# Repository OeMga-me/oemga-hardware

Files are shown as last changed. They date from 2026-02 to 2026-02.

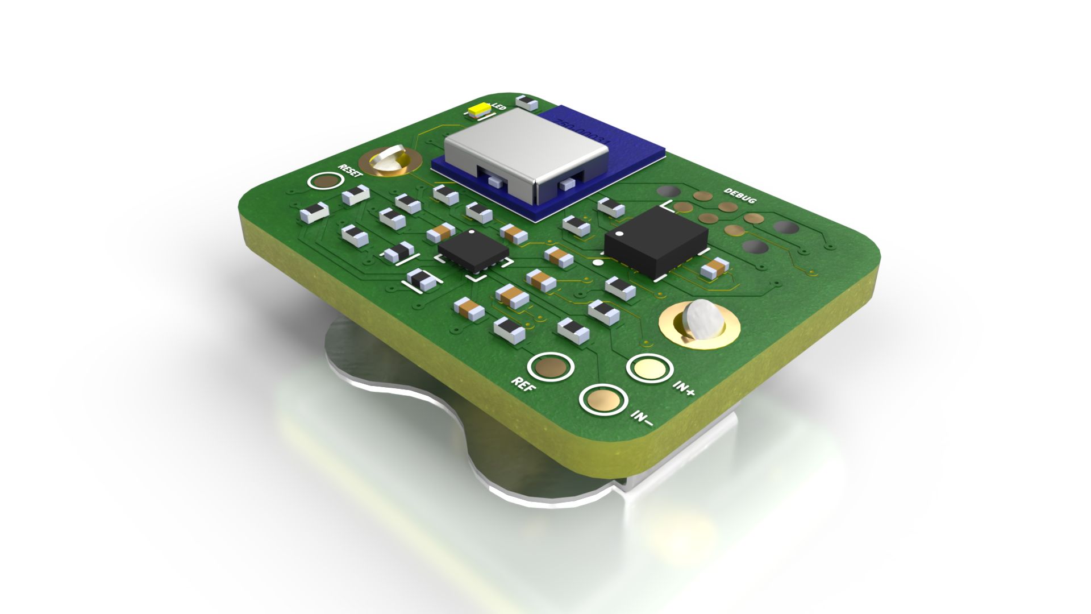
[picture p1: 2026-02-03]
hardware/Photos/1767139238420.jpeg

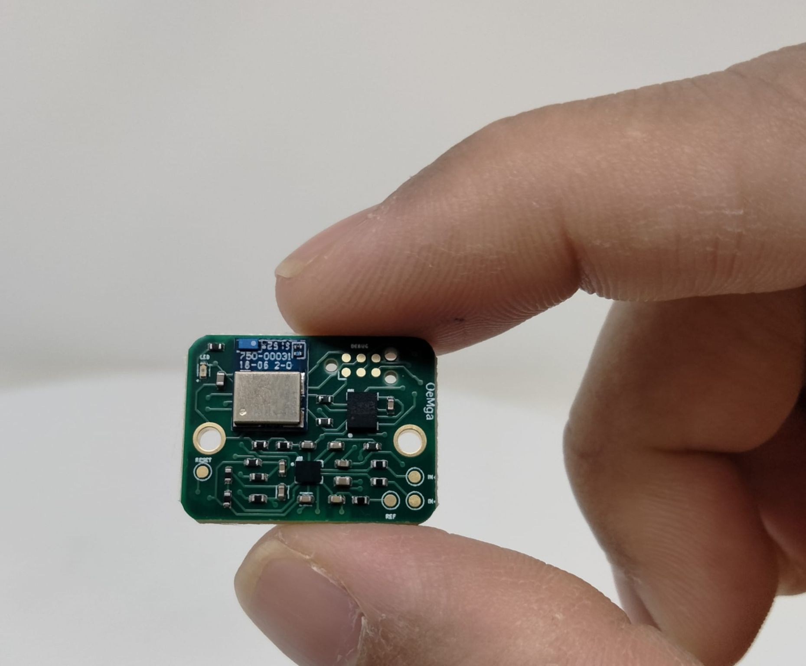
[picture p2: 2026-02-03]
hardware/Photos/1769923947562.jpeg

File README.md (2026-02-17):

<h1 align="center">OeMga.me Hardware</h1>

<p align="center">



</p>

<p align="center">
<strong>The open-source, on-device teachable bio-interaction platform.</strong>
</p>

OeMga
Copyright 2026 Adithya Pamulaparthi. Licensed under CERN-OHL-S v2.

[View Interactive 3D Model](hardware/CAD/Assembly.STL)

## The Vision
Current wearables demand that we speak their language. OeMga.me learns ours.

Today’s bio-sensors with rigid FSMs and pre-trained models, force the user to conform to the machine’s limitations. OeMga.me dismantles this paradigm. We are building the first **Teachable Bio-Interaction Platform**, where intelligence lives at the edge and evolves with you.

## The Foundation: OeMga $\alpha$
This repository hosts the open-source hardware files for the foundational module of the OeMga $\alpha$ platform: a high-precision, teachable EMG sensor.

<p align="center">
  
</p>

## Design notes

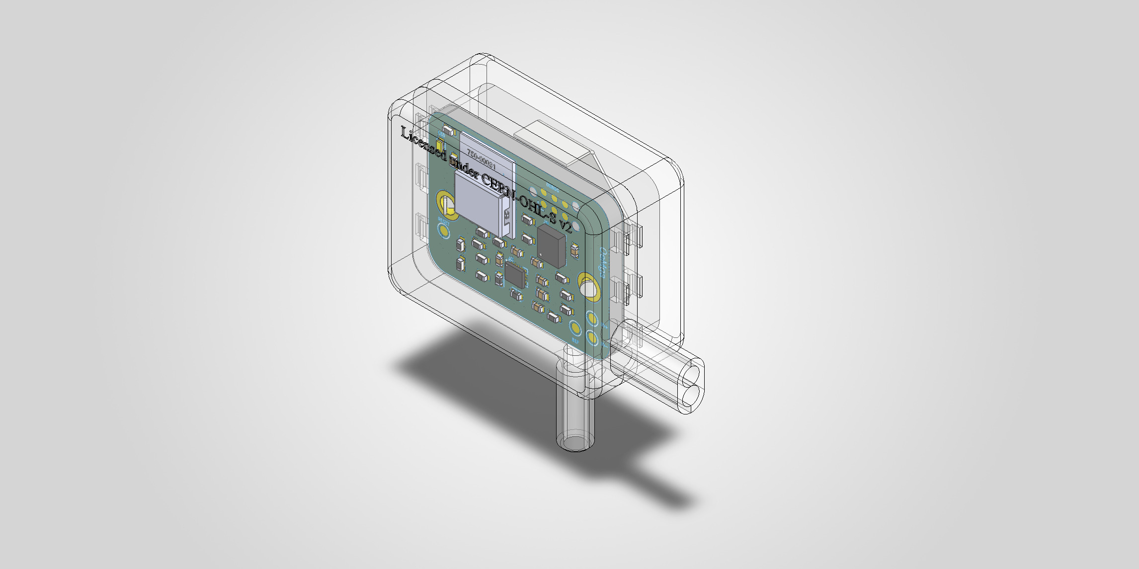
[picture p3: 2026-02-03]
hardware/CAD/Assem1.JPG

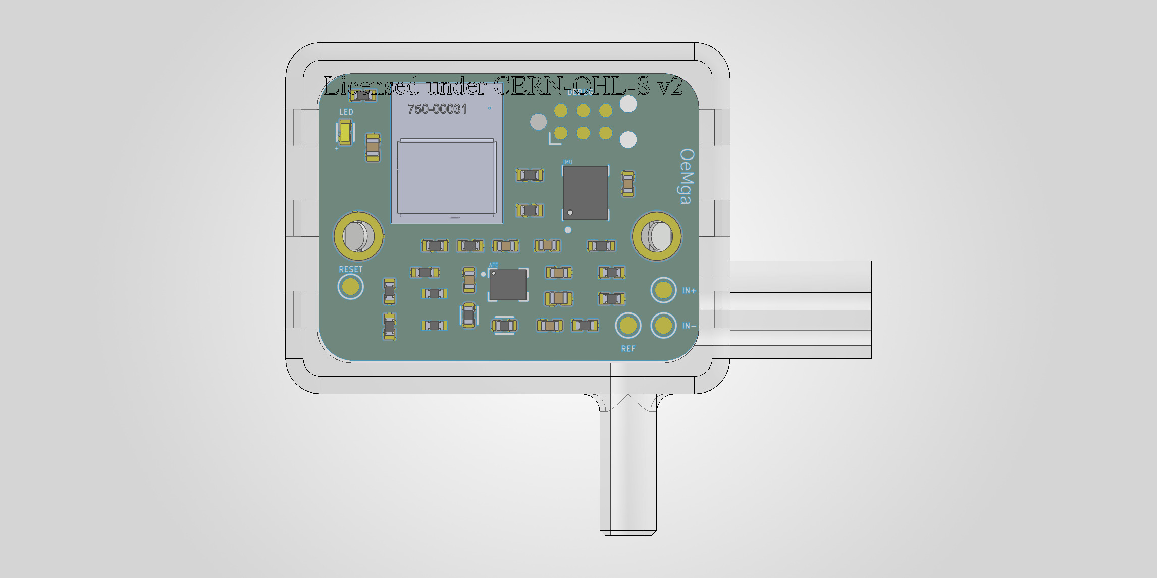
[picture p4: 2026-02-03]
hardware/CAD/Assem2.JPG

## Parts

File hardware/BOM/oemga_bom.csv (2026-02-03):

Designator | Footprint | Quantity | Value | LCSC Part #
10UF1 | CAPC1005X70N | 1 | CL10A106MQ8NNNC
BL54L15U1 | Ezurio, BL54L15u Module, Platform Side | 1 | bl54l15u
BT2 | BAT_3013 | 1 | 3013
C1, C_12 | CAPC1005X55N | 2 | CL05B104KO5NNNC
C_1 | CAPC1005X55N | 1 | CL05B102KB5NNNC
C_11 | CAPC1005X55N | 1 | CL05A105KP5NNNC
C_13 | CAPC1005X70N | 1 | CL05A106MQ5NUNC
C_4, C_7 | CAPC1005X55N | 2 | CL05B224KO5NNNC
C_8 | CAPC1005X55N | 1 | CC0402KRX7R9BB202
C_9 | CAPC1005X55N | 1 | CC0402KRX7R7BB183
D1 | LEDC1005X35N | 1 | VLMG1500-GS08
R1, R3 | RESC1005X40N | 2 | 0402WGF4701TCE
R2 | RESC1005X40N | 1 | 0402WGF1001TCE
R_12 | RES_ERJ2RKF3302X | 1 | ERJ2RKF3302X
R_13, R_16 | RES_CRCW0402_VIS | 2 | CRCW040250K0FKED
R_14 | RES_ERJ-2GEJ335X | 1 | ERJ-2GEJ335X
R_17, R_18 | RESC1005X40N | 2 | RC0402FR-0710ML
R_19 | RESC1005X40N | 1 | RC0402FR-071ML
R_2 | RESC1005X40N | 1 | CRCW0402499KFKED
R_20 | RESC1005X40N | 1 | RC0402FR-0775KL
R_6, R_7 | RESC1005X37N | 2 | AC0402FR-07182KL
U1 | BGA20N40P5X4_204X170X56N | 1 | AD8233ACBZ-R7
U2 | PQFN50P250X300X86-14N | 1 | LSM6DSOXTR

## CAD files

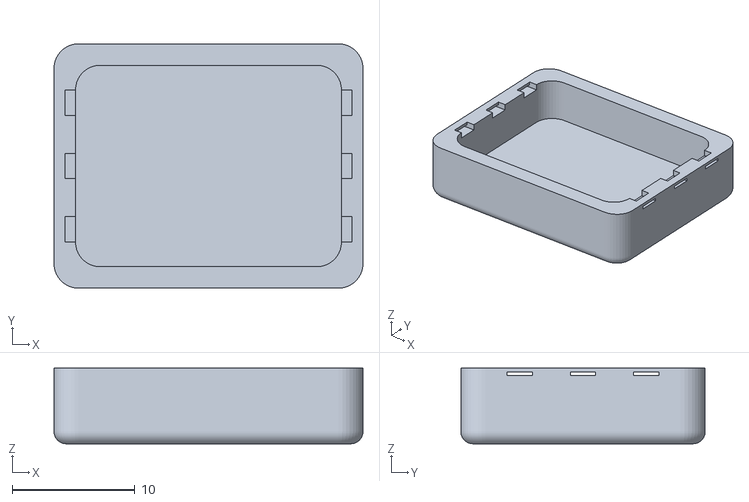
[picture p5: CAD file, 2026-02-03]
hardware/CAD/Assembly.STL
25.1 x 19.9 x 6.15

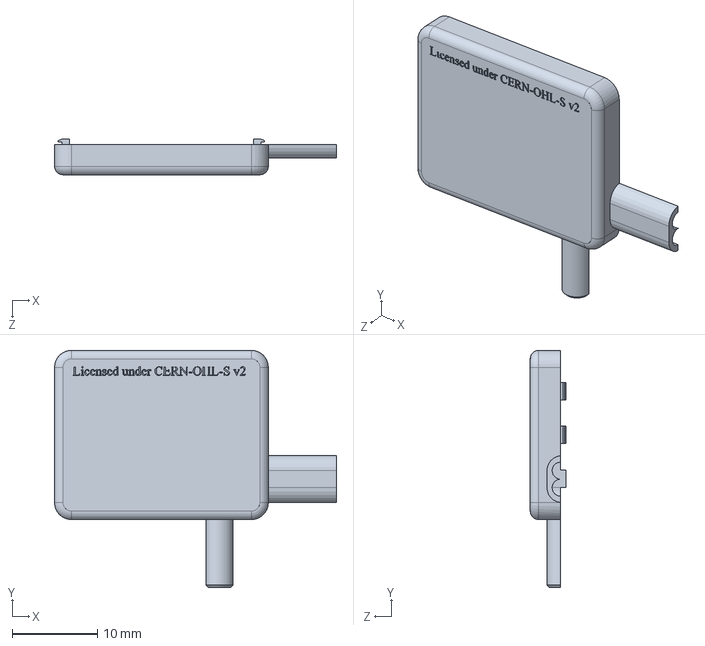
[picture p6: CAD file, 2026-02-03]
hardware/CAD/top.SLDPRT
33.1 x 27.9 x 4.19 mm

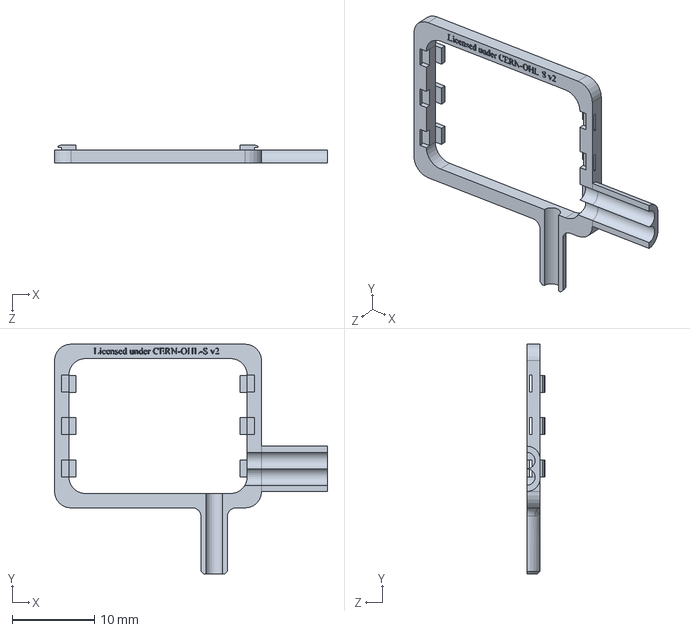
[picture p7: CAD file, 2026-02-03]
hardware/CAD/middle.SLDPRT
33.1 x 27.9 x 2.22 mm

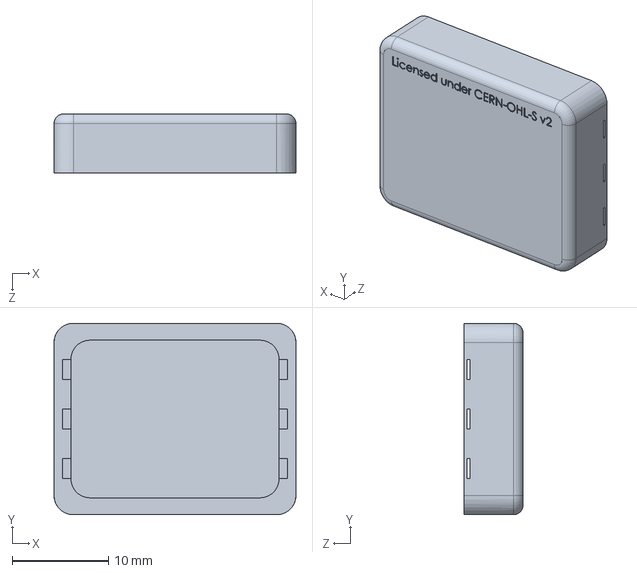
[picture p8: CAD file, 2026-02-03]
hardware/CAD/bottom.SLDPRT
25.1 x 19.9 x 6.15 mm

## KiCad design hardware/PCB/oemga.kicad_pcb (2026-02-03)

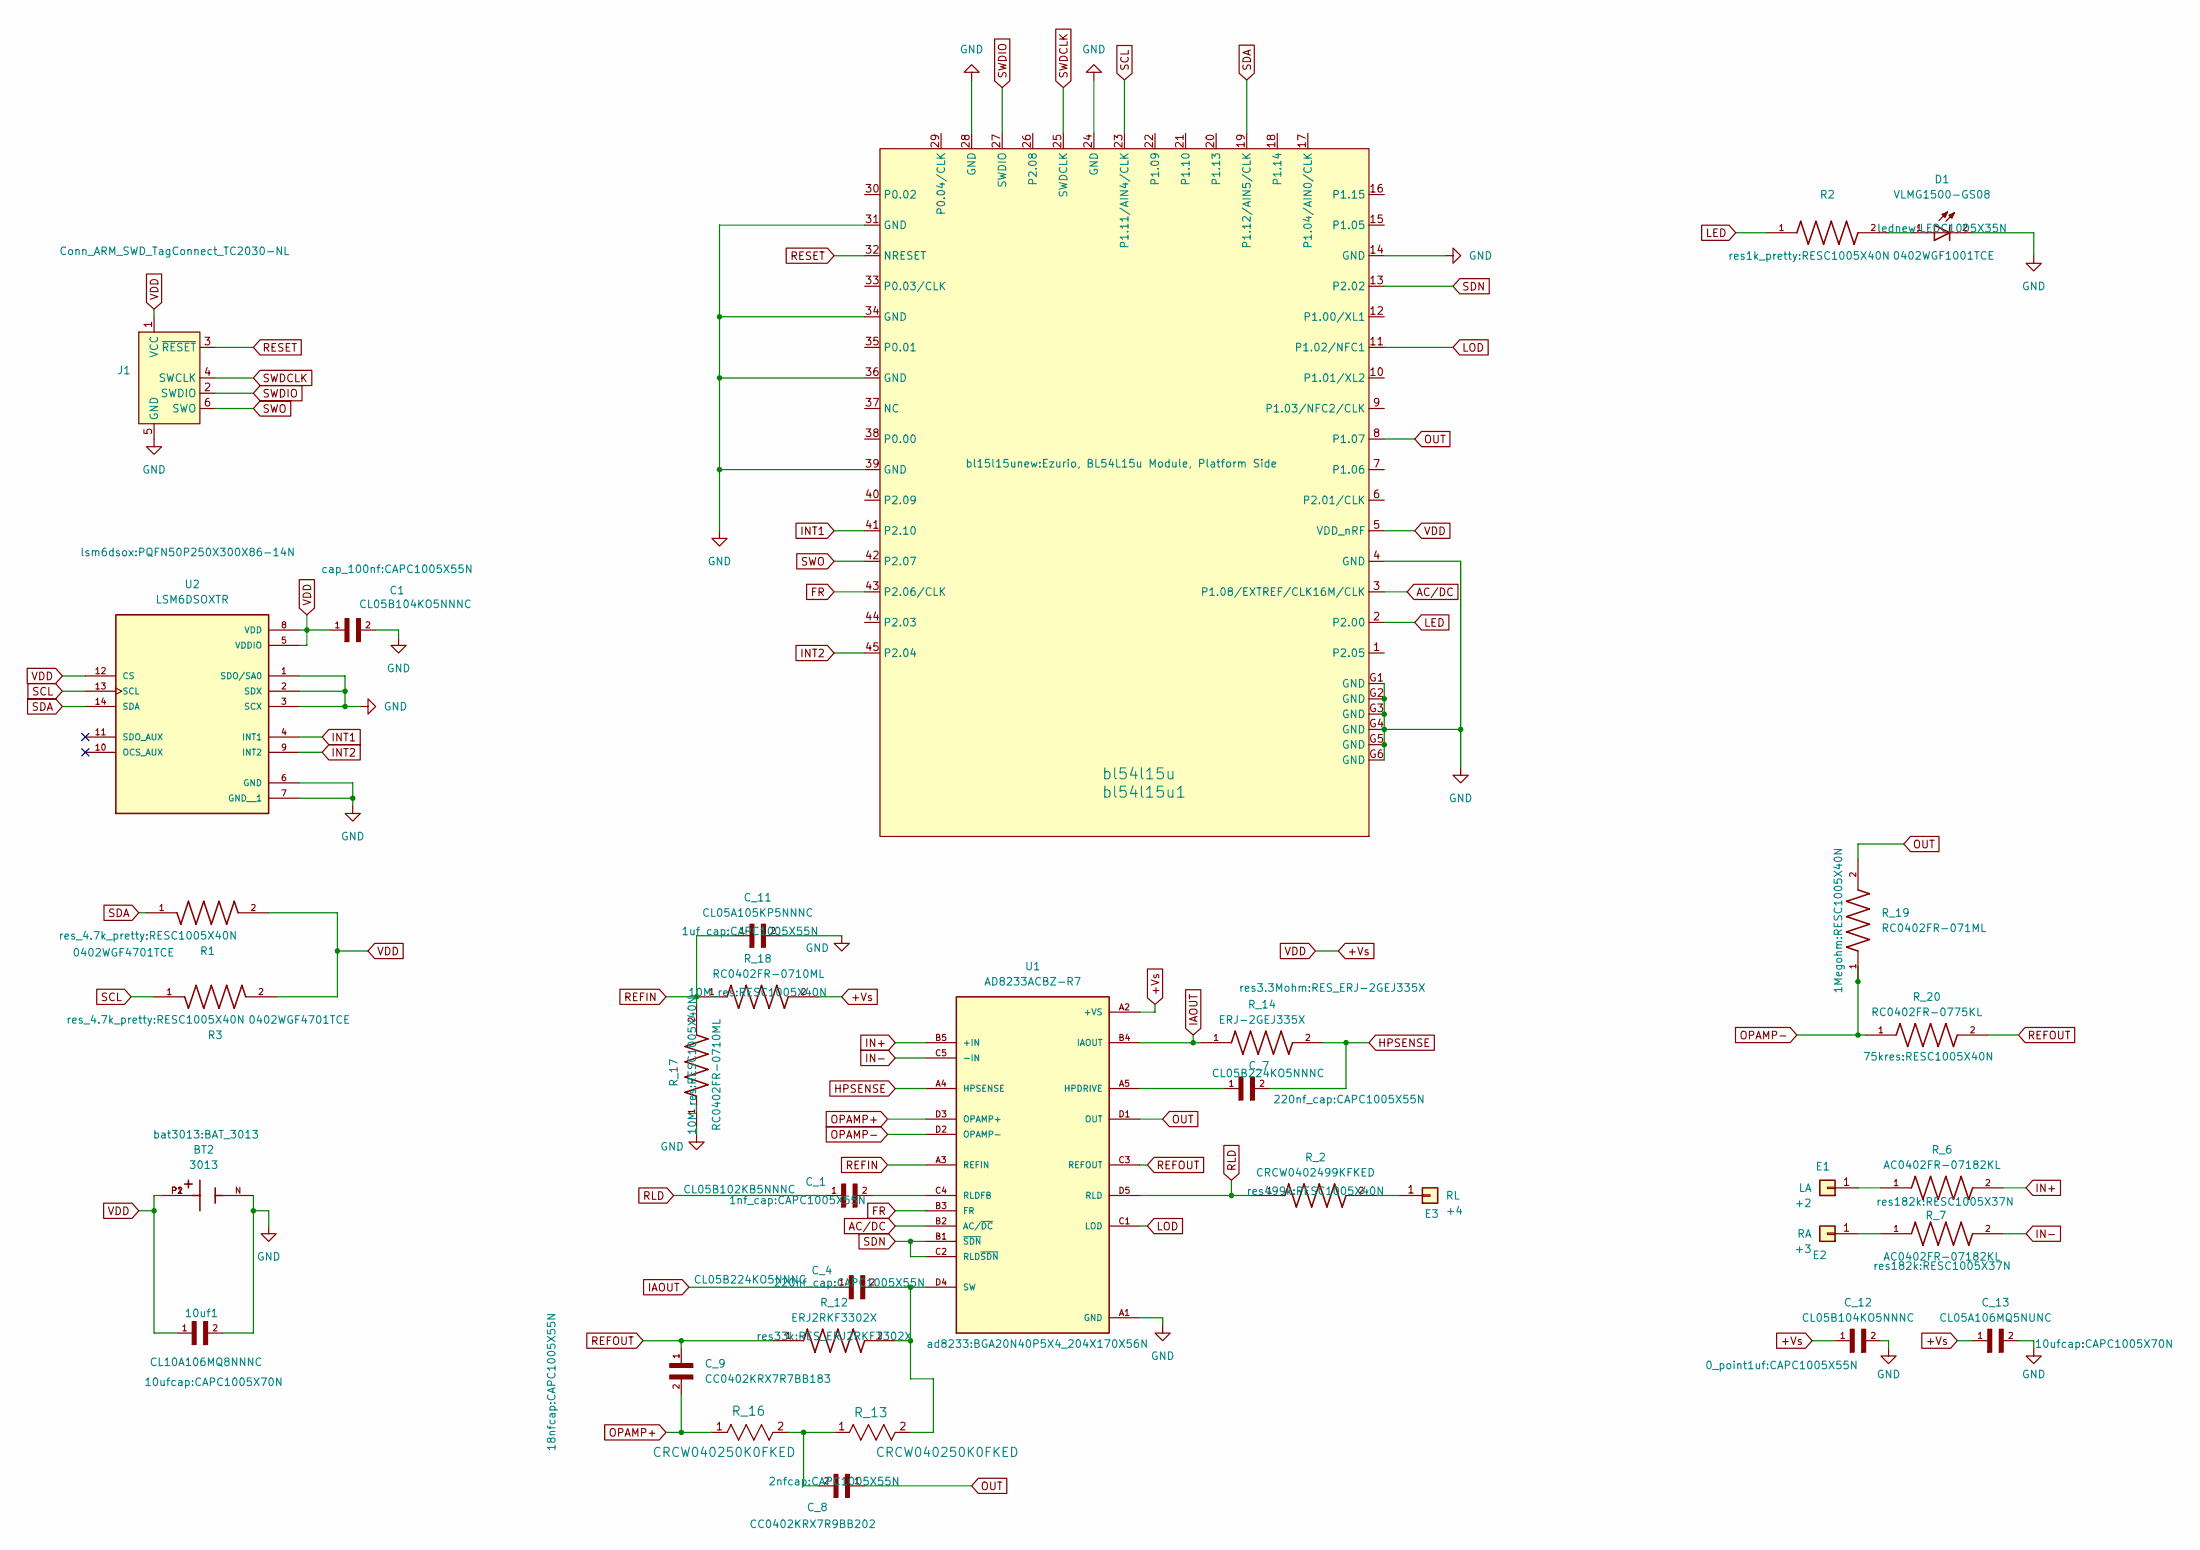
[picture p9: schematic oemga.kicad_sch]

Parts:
10uf1: CL10A106MQ8NNNC; CAPC1005X70N
+2: LA; E1
+3: RA; E2
+4: RL; E3
BT2: 3013; BAT_3013; PARTREV E
C1: CL05B104KO5NNNC; CAPC1005X55N
C_1: CL05B102KB5NNNC; CAPC1005X55N
C_4, C_7: CL05B224KO5NNNC; CAPC1005X55N
C_8: CC0402KRX7R9BB202; CAPC1005X55N; DigiKey_Part_Number 13-CC0402KRX7R9BB202CT-ND
C_9: CC0402KRX7R7BB183; CAPC1005X55N; DigiKey_Part_Number 311-1706-1-ND
C_11: CL05A105KP5NNNC; CAPC1005X55N
C_12: CL05B104KO5NNNC; CAPC1005X55N
C_13: CL05A106MQ5NUNC; CAPC1005X70N
D1: VLMG1500-GS08; LEDC1005X35N; PARTREV 1.4
J1: Conn_ARM_SWD_TagConnect_TC2030-NL; Tag-Connect_TC2030-IDC-NL_2x03_P1.27mm_Vertical
R1, R3: 0402WGF4701TCE; RESC1005X40N; PARTREV V3
R2: 0402WGF1001TCE; RESC1005X40N; PARTREV V3
R_2: CRCW0402499KFKED; RESC1005X40N
R_6, R_7: AC0402FR-07182KL; RESC1005X37N; DigiKey_Part_Number 13-AC0402FR-07182KLCT-ND
R_12: ERJ2RKF3302X; RES_ERJ2RKF3302X; PARTREV 3/1/2020
R_13, R_16: CRCW040250K0FKED; RES_CRCW0402_VIS
R_14: ERJ-2GEJ335X; RES_ERJ-2GEJ335X; PARTREV 3/1/2020
R_17, R_18: RC0402FR-0710ML; RESC1005X40N
R_19: RC0402FR-071ML; RESC1005X40N; PARTREV Nov-2024; DigiKey_Part_Number 311-1.00MLRCT-ND
R_20: RC0402FR-0775KL; RESC1005X40N; DigiKey_Part_Number 311-75KLRCT-ND
U1: AD8233ACBZ-R7; BGA20N40P5X4_204X170X56N; PARTREV 0
U2: LSM6DSOXTR; PQFN50P250X300X86-14N; PARTREV 3.0
bl54l15u1: bl54l15u; Ezurio, BL54L15u Module, Platform Side

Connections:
+Vs: 10uf1.1, BT2.P1, BT2.P2, C1.1, C_12.1, C_13.1, J1.1 (VCC), R1.2, R3.2, R_18.2, U1.A2 (+VS), U2.5 (VDDIO), U2.8 (VDD), U2.12 (CS), bl54l15u1.5 (VDD_nRF)
AC/DC: U1.B2 (AC/~DC), bl54l15u1.3 (P1.08/EXTREF/CLK16M/CLK)
FR: U1.B3 (FR), bl54l15u1.43 (P2.06/CLK)
GND: 10uf1.2, BT2.N, C1.2, C_11.2, C_12.2, C_13.2, D1.2, J1.5 (GND), R_17.1, U1.A1 (GND), U2.1 (SDO/SA0), U2.2 (SDX), U2.3 (SCX), U2.6 (GND), U2.7 (GND__1), bl54l15u1.4 (GND), bl54l15u1.14 (GND), bl54l15u1.24 (GND), bl54l15u1.28 (GND), bl54l15u1.31 (GND), bl54l15u1.34 (GND), bl54l15u1.36 (GND), bl54l15u1.39 (GND), bl54l15u1.G1 (GND), bl54l15u1.G2 (GND), bl54l15u1.G3 (GND), bl54l15u1.G4 (GND), bl54l15u1.G5 (GND), bl54l15u1.G6 (GND)
HPSENSE: C_7.2, R_14.2, U1.A4 (HPSENSE)
IAOUT: C_4.1, R_14.1, U1.B4 (IAOUT)
IN+: R_6.2, U1.B5 (+IN)
IN-: R_7.2, U1.C5 (-IN)
INT1: U2.4 (INT1), bl54l15u1.41 (P2.10)
INT2: U2.9 (INT2), bl54l15u1.45 (P2.04)
LED: R2.1, bl54l15u1.2 (P2.00)
LOD: U1.C1 (LOD), bl54l15u1.11 (P1.02/NFC1)
unnamed: +2.1, R_6.1
unnamed: +3.1, R_7.1
unnamed: +4.1, R_2.2
unnamed: C_8.2, R_13.1, R_16.2
unnamed: D1.1, R2.2
unnamed: C_7.1, U1.A5 (HPDRIVE)
unnamed: C_1.2, U1.C4 (RLDFB)
unnamed: C_4.2, R_12.2, R_13.2, U1.D4 (SW)
OPAMP+: C_9.2, R_16.1, U1.D3 (OPAMP+)
OPAMP-: R_19.1, R_20.1, U1.D2 (OPAMP-)
OUT: C_8.1, R_19.2, U1.D1 (OUT), bl54l15u1.8 (P1.07)
REFIN: C_11.1, R_17.2, R_18.1, U1.A3 (REFIN)
REFOUT: C_9.1, R_12.1, R_20.2, U1.C3 (REFOUT)
RESET: J1.3 (~RESET), bl54l15u1.32 (NRESET)
RLD: C_1.1, R_2.1, U1.D5 (RLD)
SCL: R3.1, U2.13 (SCL), bl54l15u1.23 (P1.11/AIN4/CLK)
SDA: R1.1, U2.14 (SDA), bl54l15u1.19 (P1.12/AIN5/CLK)
SDN: U1.B1 (~SDN), U1.C2 (RLD~SDN), bl54l15u1.13 (P2.02)
SWDCLK: J1.4 (SWCLK), bl54l15u1.25 (SWDCLK)
SWDIO: J1.2 (SWDIO), bl54l15u1.27 (SWDIO)
SWO: J1.6 (SWO), bl54l15u1.42 (P2.07)

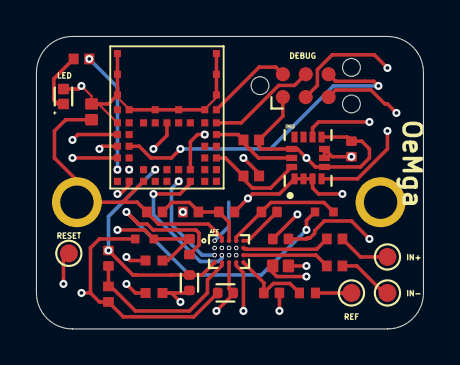
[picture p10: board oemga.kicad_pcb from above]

Board: 6 copper layers, 21.5 x 16.2 mm, 30 parts (1 on the bottom side), 30 nets.

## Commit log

2026-02-03 Initial release: v1.0 hardware with CERN-OHL-S license
    [oemga.kicad_pcb, oemga.kicad_sch]
2026-02-03 Initial release: v1.0 CAD
    [bottom.SLDPRT, middle.SLDPRT, top.SLDPRT]
2026-02-03 Assembly STL
    [Assembly.STL]

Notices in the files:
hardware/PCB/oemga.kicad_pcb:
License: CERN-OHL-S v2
